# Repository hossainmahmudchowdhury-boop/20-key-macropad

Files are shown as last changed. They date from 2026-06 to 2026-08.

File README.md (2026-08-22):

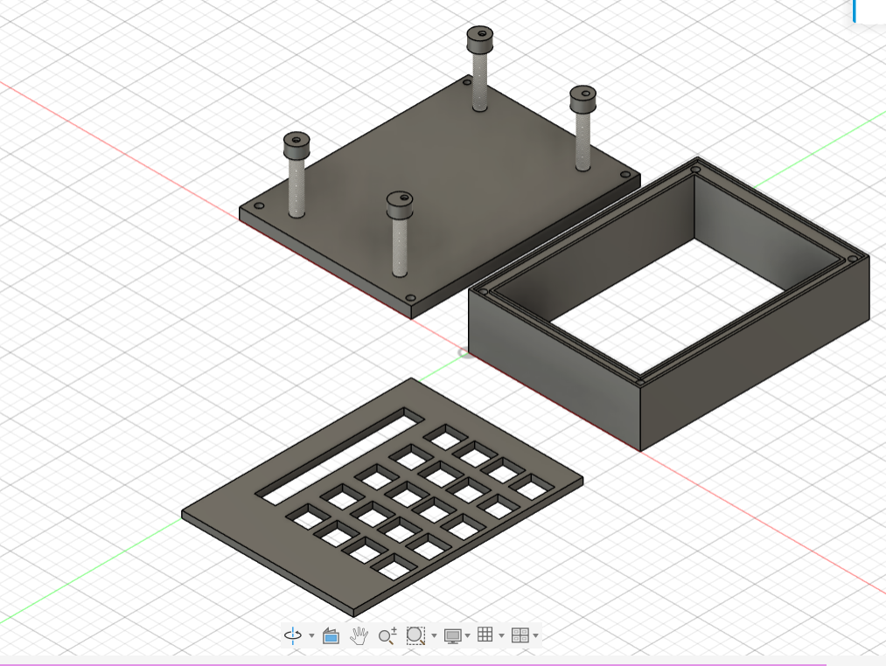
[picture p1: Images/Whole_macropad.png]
image alt

# 20-key-macropad

I have designed a functional macropad design mostly for programming enthusiastics. This design contains 4x5 grid which contains 20 keycaps . Anyone can customize it according to their need . In PCB I have used Seeduino XIAO and for this you can customized the keys in AHK. A potentiometer is also added for operating the macropad with simple matrix design

## Hardware Used

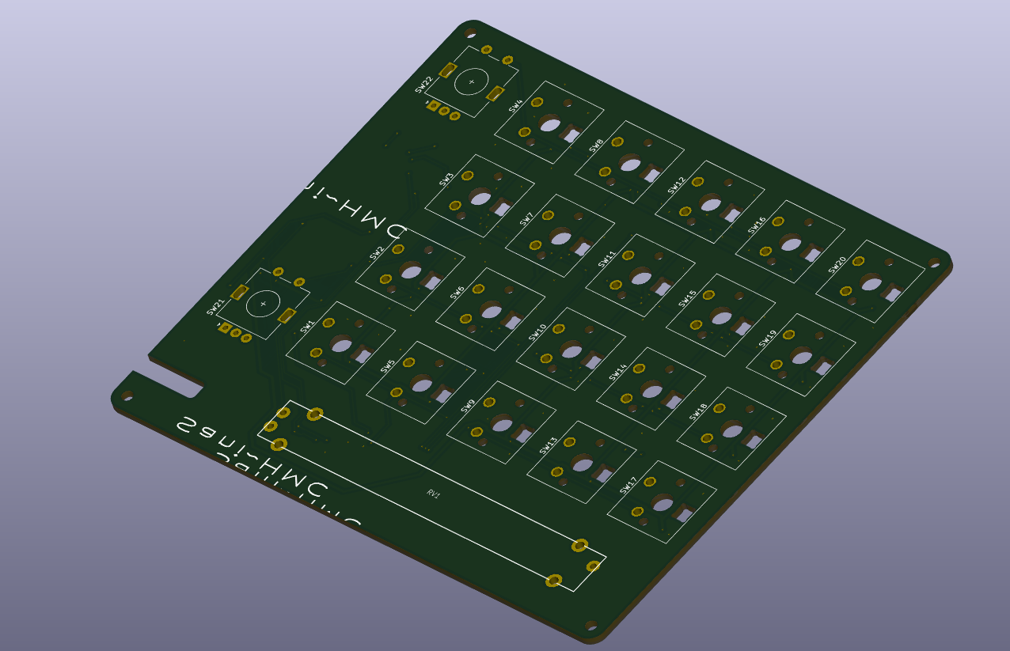
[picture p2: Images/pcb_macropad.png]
image alt

##### Schematic 
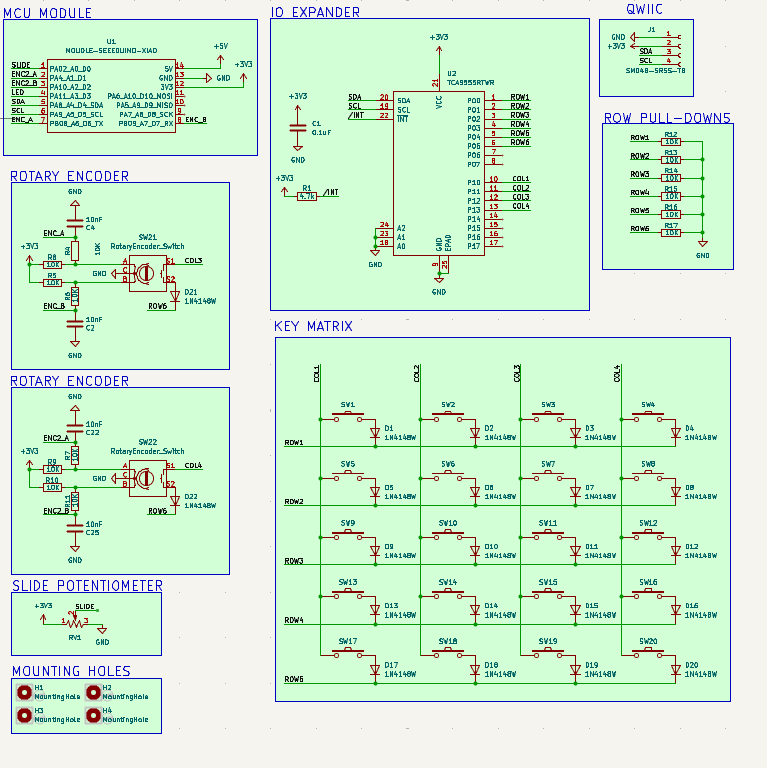
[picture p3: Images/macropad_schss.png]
image alt


#### 1.Seeduino XIAO (MCU)
#### 2.20 × Mechanical Switches
#### 3.20 × Diodes 
#### 4.I/O Expander (for additional key inputs)
#### 5.USB Interface

## Case Design _
As this project emphasizes short way to conduct any command , I made my own custom case in three parts ,
the base one and the top part contain 75mm width and 100mm . The hight of the total case is 32mm  .

### Top Case
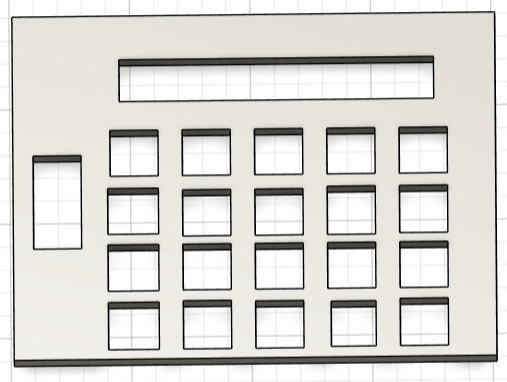
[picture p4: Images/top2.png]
image alt


### Middle Case
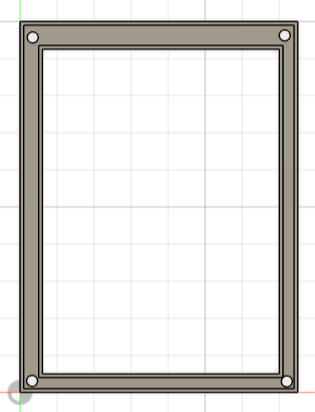
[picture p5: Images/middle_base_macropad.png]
image alt


### Base Case 
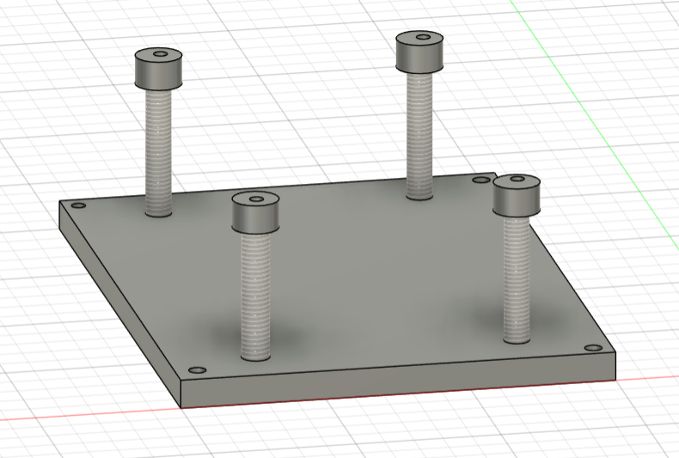
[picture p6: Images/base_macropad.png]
image alt


### Key Cap

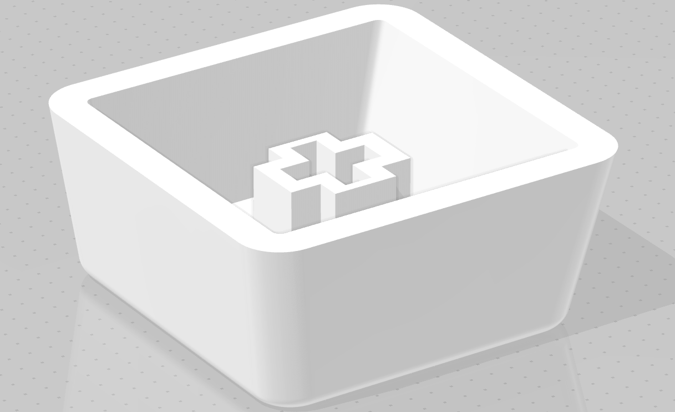
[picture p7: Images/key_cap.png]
image alt


## Software
In this hardware design I use KiCad (Version 10.0) for PCB integration . For case design I have used Fusion . 

## BOM

| Item | Quantity | Price | Link |
|---|---|---|---|
| SEEED XIAO RP2040 (THT) | 1 | $$7.25 | [Link](https://www.seeedstudio.com/XIAO-RP2040-v1-0-p-5026.html) |
| Outemu Silent Peach V3 Switch | 10 | $6.09 | [Link](https://www.aliexpress.com/item/1005006905361113.html) |
| SK6812-MINI-E (RGB LEDs) | 25 | $5.26 | [Link](https://www.aliexpress.com/item/1005005193716172.html) |
| 1N4148 Diode | 100 | $1.20 | [Link](https://www.aliexpress.com/item/4000142272546.html) |
| SSD1306 OLED Display | 1 | $5.15 | [Link](https://www.aliexpress.com/item/1005008640132638.html) |
| YMDK Blank DSA 1u Keycap | 20 | $12.86 | [Link](https://www.aliexpress.com/item/32842379355.html) |
| 45mm Straight Side Potentiometer | 1 | 3.15$ | [Link](https://alishort.com/0HUxU) |
| EC 11 Encoder with Push Button Half Handle 20MM Shaft | 5 | $6.31 | [Link](https://www.aliexpress.com/item/1005005983134515.html) |
| M3 Heat Set Inserts | 30 | $6.13 | [Link](https://www.aliexpress.com/item/1005006071488810.html) |
| M3 Fasteners | 50 | $6.28 | [Link](https://www.aliexpress.com/item/1005011845940916.html) |
| Top Case | 1 | Printing Legion |  |
| Bottom Case | 1 | Printing Legion |  |
| Middle Case | |  Printing Legion | |
| PCB | 3 | $11.02 | JLCPCB |

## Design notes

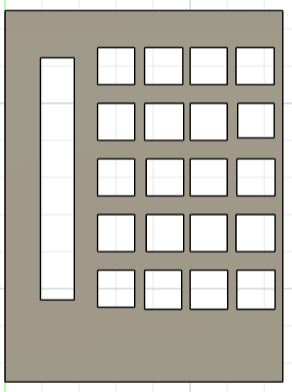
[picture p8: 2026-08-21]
Images/top_macropad.png

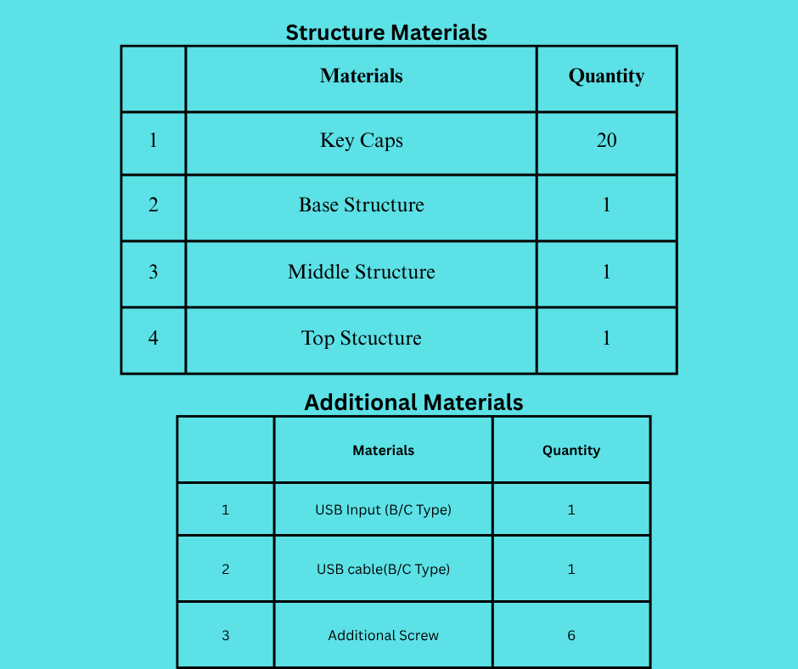
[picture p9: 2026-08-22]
Images/rough_2.png

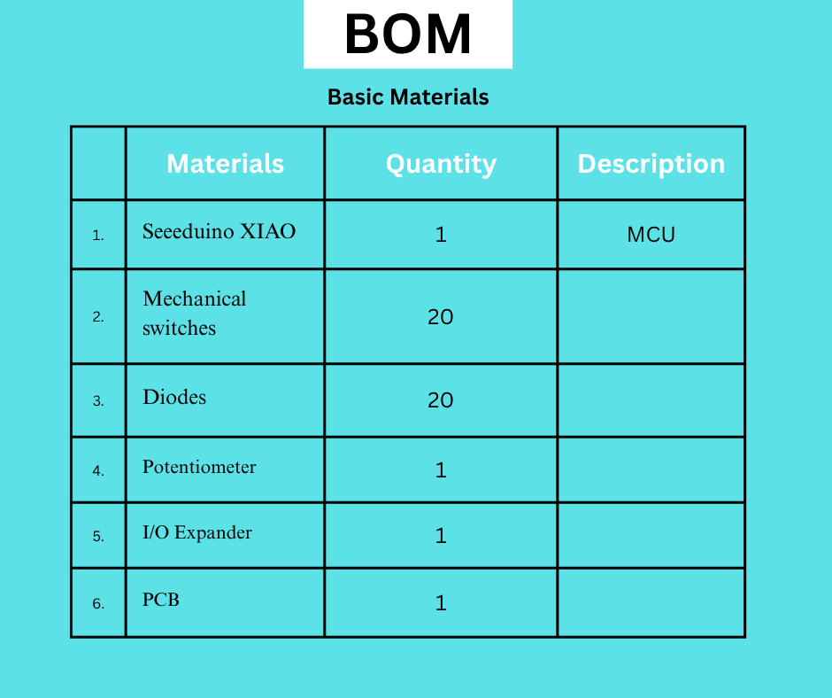
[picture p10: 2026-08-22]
Images/rough_1.png

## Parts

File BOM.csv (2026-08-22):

Item | Quantity | Price | Link
SEEED XIAO RP2040 (THT) | 1 | $7.25 | https://www.seeedstudio.com/XIAO-RP2040-v1-0-p-5026.html
Outemu Silent Peach V3 Switch | 10 | $6.09 | https://www.aliexpress.com/item/1005006905361113.html
SK6812-MINI-E (RGB LEDs) | 20 | $5.26 | https://www.aliexpress.com/item/1005005193716172.html
1N4148 Diode | 100 | $1.20 | https://www.aliexpress.com/item/4000142272546.html
SSD1306 OLED Display | 1 | $5.15 | https://www.aliexpress.com/item/1005008640132638.html
YMDK Blank DSA 1u Keycap | 20 | $12.43 | https://www.aliexpress.com/item/32842379355.html
45mm Straight Side Potentiometer | 1 | 3.15$ | https://alishort.com/0HUxU
EC 11 Encoder with Push Button Half Handle 20MM Shaft | 5 | $6.31 | https://www.aliexpress.com/item/1005005983134515.html
M3 Heat Set Inserts | 30 | $6.13 | https://www.aliexpress.com/item/1005006071488810.html
M3 Fasteners | 50 | $6.28 | https://www.aliexpress.com/item/1005011845940916.html
Top Case | 1 | Printing Legion
Middle Case | 1 | Printing Legion
Bottom Case | 1 | Printing Legion
PCB | 5 | $11.02 | JLCPCB

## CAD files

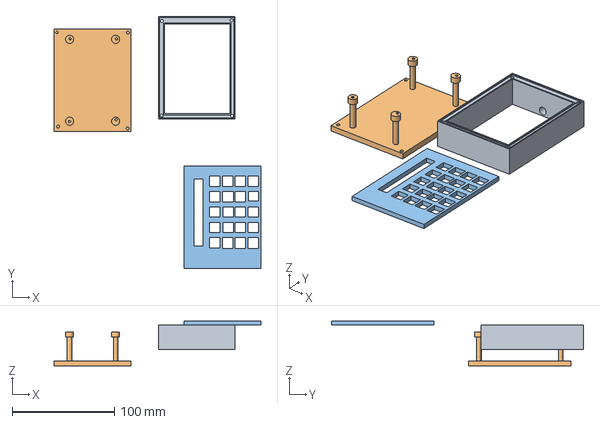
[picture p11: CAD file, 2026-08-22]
Production/Whole_case.step
201.8 x 246.2 x 43.8 mm

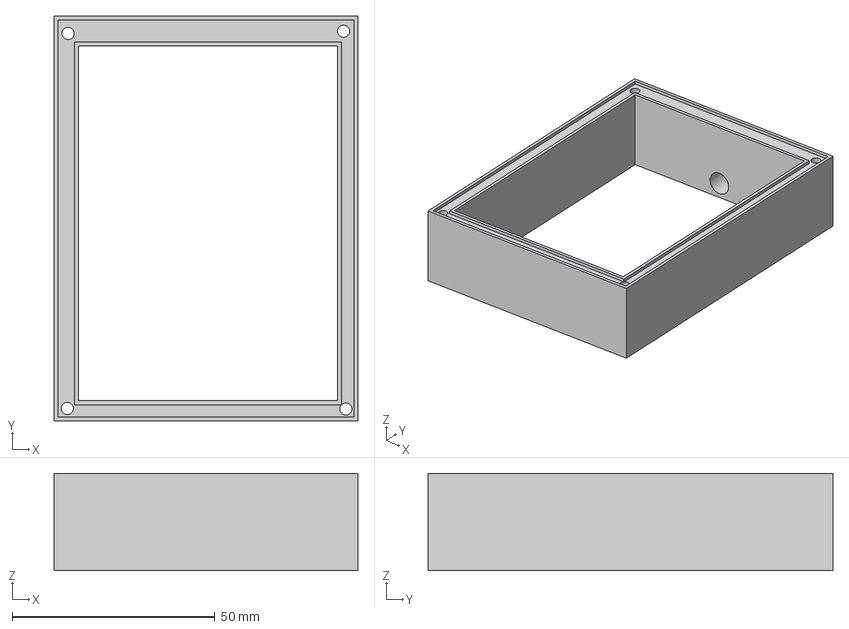
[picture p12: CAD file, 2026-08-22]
Case/middle_macropad.step
75.0 x 100.0 x 24.0 mm

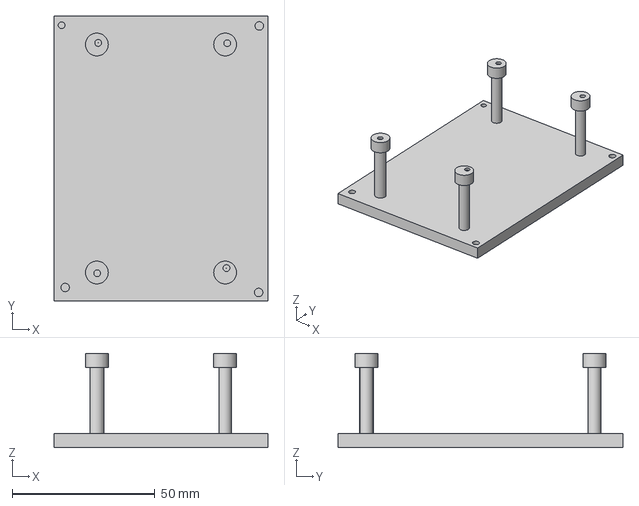
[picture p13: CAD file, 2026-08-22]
Case/base_macropad.step
75.0 x 100.0 x 33.0 mm

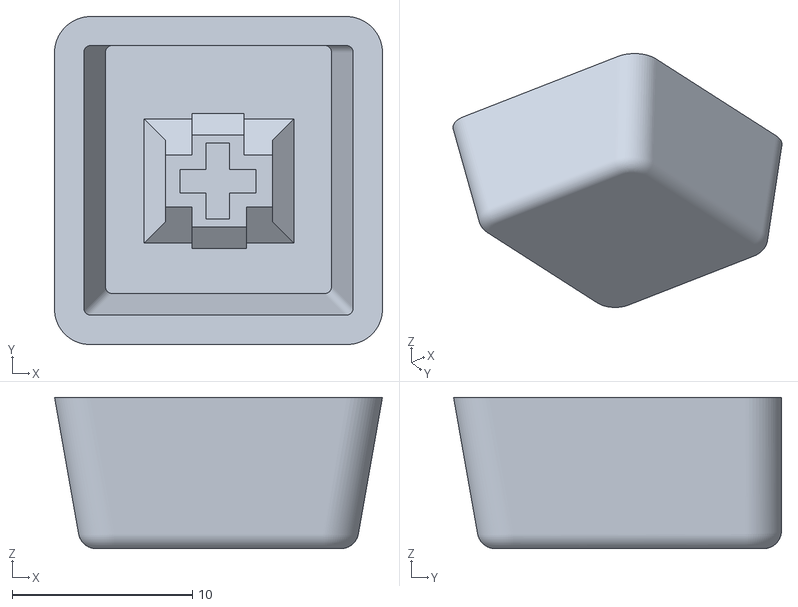
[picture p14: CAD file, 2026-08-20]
Production/Key_Cap_keypad.stl
18.2 x 18.2 x 8.40

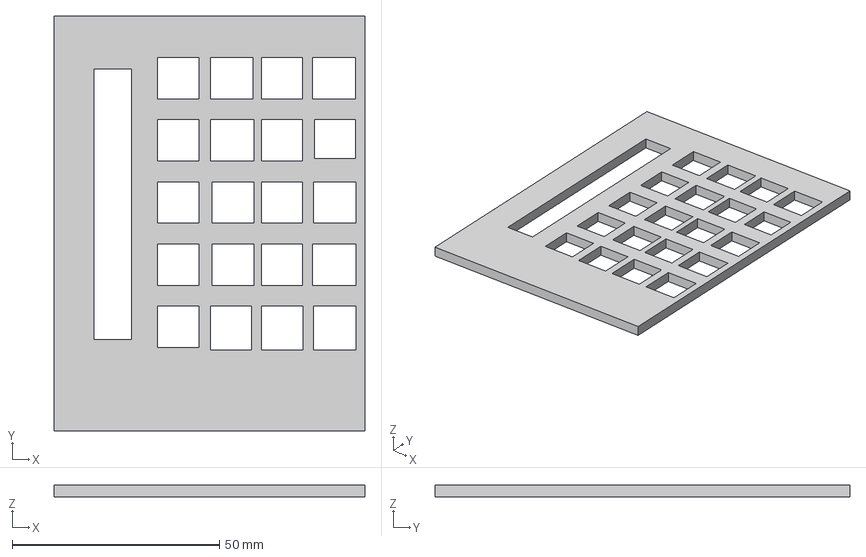
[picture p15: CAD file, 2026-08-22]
Case/top_macropad.step
75.0 x 100.1 x 3.00 mm

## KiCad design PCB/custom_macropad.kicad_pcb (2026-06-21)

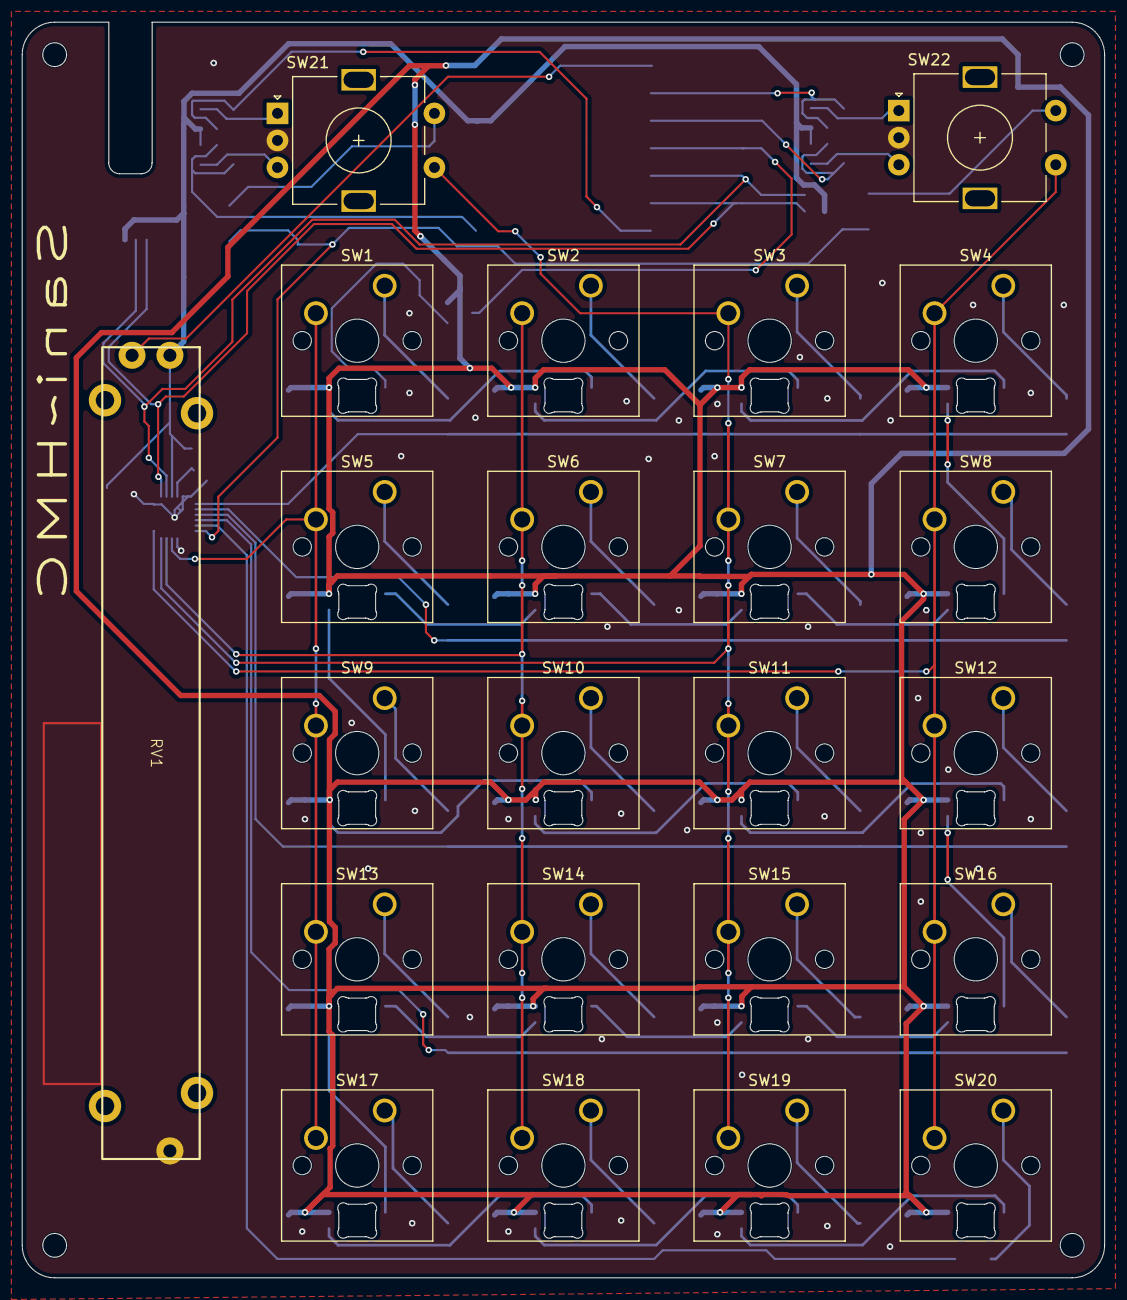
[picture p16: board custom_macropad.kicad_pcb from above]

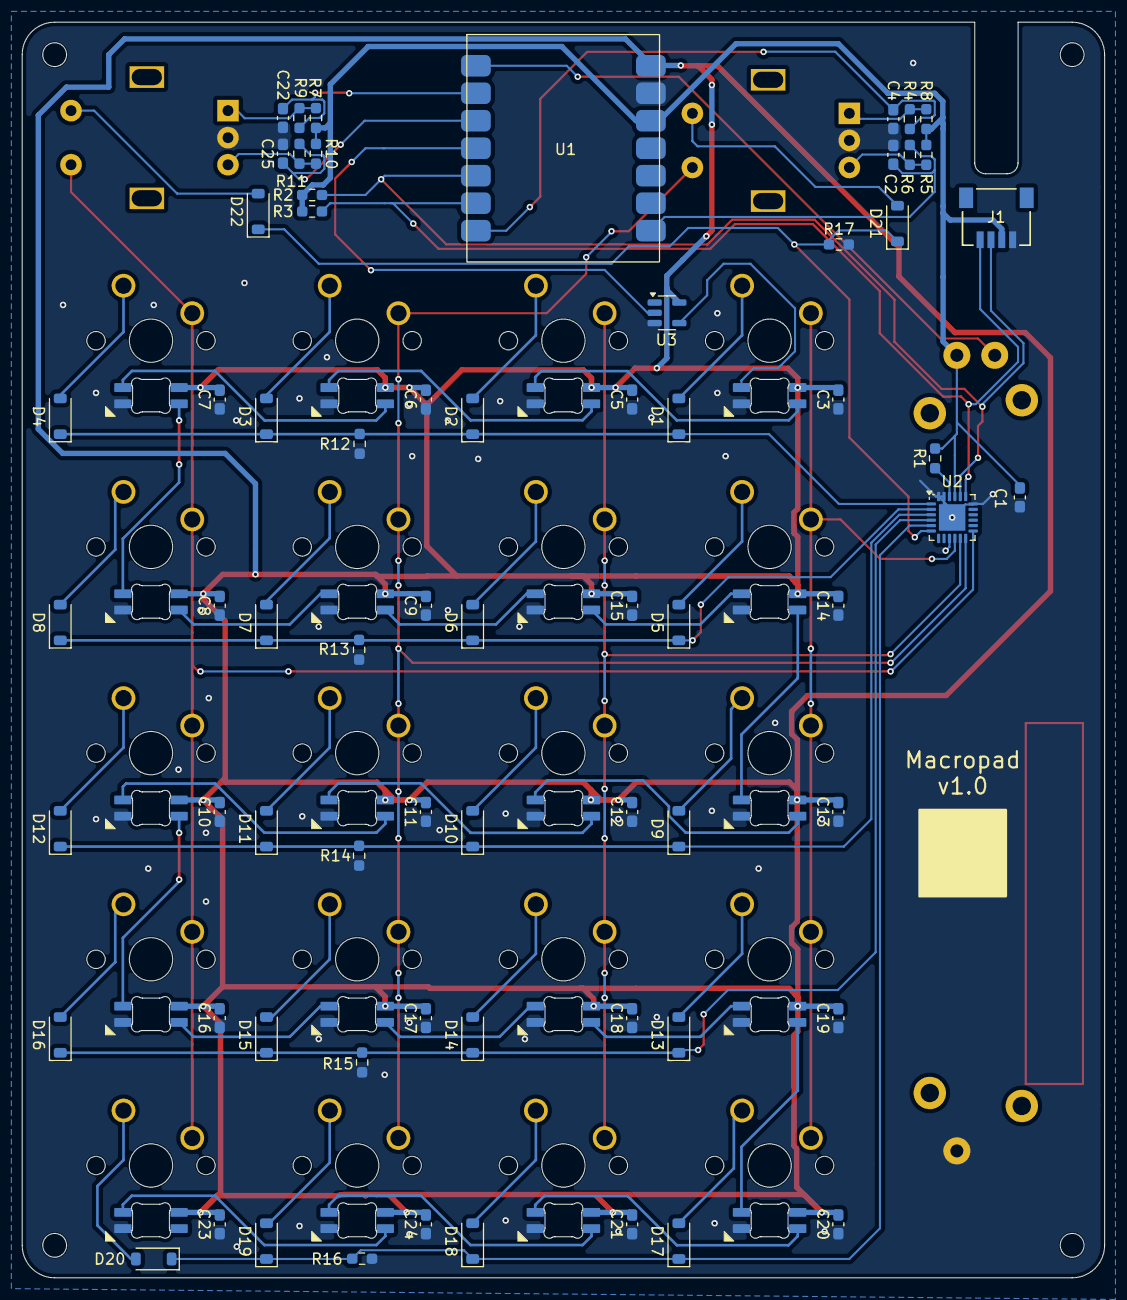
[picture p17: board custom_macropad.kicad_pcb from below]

Board: 2 copper layers, 100.0 x 116.0 mm, 115 parts (68 on the bottom side), 68 nets.

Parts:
C1, C3, C5, C6, C7, C8, C9, C10, C11, C12, C13, C14, C15, C16, C17, C18, C19, C20, C21, C23, C24: 0.1uF; C_0603_1608Metric_Pad1.08x0.95mm_HandSolder
C2, C4, C22, C25: 10nF; C_0603_1608Metric_Pad1.08x0.95mm_HandSolder
D1, D2, D3, D4, D5, D6, D7, D8, D9, D10, D11, D12, D13, D14, D15, D16, D17, D18, D19, D20, D21, D22: 1N4148W; D_SOD-123
H1, H2, H3, H4: MountingHole; MountingHole_2.2mm_M2
J1: SM04B-SRSS-TB; CONN_SM04B-SRSS-TB_JST
LED1, LED2, LED3, LED4, LED5, LED6, LED7, LED8, LED9, LED10, LED11, LED12, LED13, LED14, LED15, LED16, LED17, LED18, LED20, LED21: SK6812MINI-E; MX_SK6812MINI-E
R1, R2, R3: 4.7k; R_0603_1608Metric_Pad0.98x0.95mm_HandSolder
R4, R5, R6, R7, R8, R9, R10, R11, R12, R13, R14, R15, R16, R17: 10K; R_0603_1608Metric_Pad0.98x0.95mm_HandSolder
RV1: R_Potentiometer_US; PTA6043-2010CIB103
SW1, SW2, SW3, SW4, SW5, SW6, SW7, SW8, SW9, SW10, SW11, SW12, SW13, SW14, SW15, SW16, SW17, SW18, SW19, SW20: keyswitch; SW_Cherry_MX_1.00u_PCB
SW21, SW22: RotaryEncoder_Switch; RotaryEncoder_Alps_EC11E-Switch_Vertical_H20mm
U1: MOUDLE-SEEEDUINO-XIAO; MOUDLE14P-SMD-2.54-21X17.8MM
U2: TCA9555RTWR; WQFN-24-1EP_4x4mm_P0.5mm_EP2.45x2.45mm
U3: SN74LV1T34DBV; SOT-23-5

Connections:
+3V3: C1.1, J1.2, R1.2, R2.2, R3.2, R5.1, R8.1, R9.1, R10.1, RV1.1, U1.12 (3V3), U2.21 (VCC)
+5V: C3.2, C5.2, C6.2, C7.2, C8.2, C9.2, C10.2, C11.2, C12.2, C13.2, C14.2, C15.2, C16.2, C17.2, C18.2, C19.2, C20.2, C21.2, C23.2, C24.2, LED1.1 (VDD), LED2.1 (VDD), LED3.1 (VDD), LED4.1 (VDD), LED5.1 (VDD), LED6.1 (VDD), LED7.1 (VDD), LED8.1 (VDD), LED9.1 (VDD), LED10.1 (VDD), LED11.1 (VDD), LED12.1 (VDD), LED13.1 (VDD), LED14.1 (VDD), LED15.1 (VDD), LED16.1 (VDD), LED17.1 (VDD), LED18.1 (VDD), LED20.1 (VDD), LED21.1 (VDD), U1.14 (5V), U3.5 (VCC)
/COL1: SW1.2, SW5.2, SW9.2, SW13.2, SW17.2, U2.10
/COL2: SW2.2, SW6.2, SW10.2, SW14.2, SW18.2, U2.11
/COL3: SW3.2, SW7.2, SW11.2, SW15.2, SW19.2, SW21.S1, U2.12
/COL4: SW4.2, SW8.2, SW12.2, SW16.2, SW20.2, SW22.S1, U2.13
/ENC2_A: C22.2, R7.2, U1.2 (PA4_A1_D1)
/ENC2_B: C25.1, R11.1, U1.3 (PA10_A2_D2)
/ENC_A: C4.2, R4.2, U1.7 (PB08_A6_D6_TX)
/ENC_B: C2.1, R6.1, U1.8 (PB09_A7_D7_RX)
/LED: U1.4 (PA11_A3_D3), U3.2 (A)
/LED_5V: LED1.4 (DIN), U3.4 (Y)
/ROW1: D1.1 (K), D2.1 (K), D3.1 (K), D4.1 (K), R12.1, U2.1 (P00)
/ROW2: D5.1 (K), D6.1 (K), D7.1 (K), D8.1 (K), R13.1, U2.2 (P01)
/ROW3: D9.1 (K), D10.1 (K), D11.1 (K), D12.1 (K), R14.1, U2.3 (P02)
/ROW4: D13.1 (K), D14.1 (K), D15.1 (K), D16.1 (K), R15.1, U2.4 (P03)
/ROW5: D17.1 (K), D18.1 (K), D19.1 (K), D20.1 (K), R16.1, U2.5 (P04)
/ROW6: D21.1 (K), D22.1 (K), R17.1, U2.6 (P05)
/SCL: J1.4, R3.1, U1.6 (PA9_A5_D5_SCL), U2.19 (SCL)
/SDA: J1.3, R2.1, U1.5 (PA8_A4_D4_SDA), U2.20 (SDA)
/SLIDE: RV1.2, U1.1 (PA02_A0_D0)
//INT: R1.1, U2.22 (~INT)
GND: C1.2, C2.2, C3.1, C4.1, C5.1, C6.1, C7.1, C8.1, C9.1, C10.1, C11.1, C12.1, C13.1, C14.1, C15.1, C16.1, C17.1, C18.1, C19.1, C20.1, C21.1, C22.1, C23.1, C24.1, C25.2, J1.1, LED1.3 (VSS), LED2.3 (VSS), LED3.3 (VSS), LED4.3 (VSS), LED5.3 (VSS), LED6.3 (VSS), LED7.3 (VSS), LED8.3 (VSS), LED9.3 (VSS), LED10.3 (VSS), LED11.3 (VSS), LED12.3 (VSS), LED13.3 (VSS), LED14.3 (VSS), LED15.3 (VSS), LED16.3 (VSS), LED17.3 (VSS), LED18.3 (VSS), LED20.3 (VSS), LED21.3 (VSS), R12.2, R13.2, R14.2, R15.2, R16.2, R17.2, RV1.3, SW21.C, SW22.C, U1.13 (GND), U2.9 (GND), U2.18 (A0), U2.23 (A1), U2.24 (A2), U2.25 (EPAD), U3.3 (GND)
unnamed: D1.2 (A), SW1.1
unnamed: D2.2 (A), SW2.1
unnamed: D3.2 (A), SW3.1
unnamed: D4.2 (A), SW4.1
unnamed: D5.2 (A), SW5.1
unnamed: D6.2 (A), SW6.1
unnamed: D7.2 (A), SW7.1
unnamed: D8.2 (A), SW8.1
unnamed: D9.2 (A), SW9.1
unnamed: D10.2 (A), SW10.1
unnamed: D11.2 (A), SW11.1
unnamed: D12.2 (A), SW12.1
unnamed: D13.2 (A), SW13.1
unnamed: D14.2 (A), SW14.1
unnamed: D15.2 (A), SW15.1
unnamed: D16.2 (A), SW16.1
unnamed: D17.2 (A), SW17.1
unnamed: D18.2 (A), SW18.1
unnamed: D19.2 (A), SW19.1
unnamed: D20.2 (A), SW20.1
unnamed: D21.2 (A), SW21.S2
unnamed: D22.2 (A), SW22.S2
unnamed: LED1.2 (DOUT), LED2.4 (DIN)
unnamed: LED2.2 (DOUT), LED3.4 (DIN)
unnamed: LED3.2 (DOUT), LED4.4 (DIN)
unnamed: LED4.2 (DOUT), LED5.4 (DIN)
unnamed: LED5.2 (DOUT), LED6.4 (DIN)
unnamed: LED6.2 (DOUT), LED7.4 (DIN)
unnamed: LED7.2 (DOUT), LED8.4 (DIN)
unnamed: LED8.2 (DOUT), LED9.4 (DIN)
unnamed: LED9.2 (DOUT), LED10.4 (DIN)
unnamed: LED10.2 (DOUT), LED11.4 (DIN)
unnamed: LED11.2 (DOUT), LED12.4 (DIN)
unnamed: LED12.2 (DOUT), LED13.4 (DIN)
unnamed: LED13.2 (DOUT), LED14.4 (DIN)
unnamed: LED14.2 (DOUT), LED15.4 (DIN)
unnamed: LED15.2 (DOUT), LED16.4 (DIN)
unnamed: LED16.2 (DOUT), LED17.4 (DIN)
unnamed: LED17.2 (DOUT), LED18.4 (DIN)
unnamed: LED18.2 (DOUT), LED21.4 (DIN)
unnamed: LED20.4 (DIN), LED21.2 (DOUT)
unnamed: R4.1, R8.2, SW21.A
unnamed: R5.2, R6.2, SW21.B
unnamed: R7.1, R9.2, SW22.A
unnamed: R10.2, R11.2, SW22.B

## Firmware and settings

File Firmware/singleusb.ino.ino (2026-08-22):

#include <Adafruit_TinyUSB.h>

// Define the button pin
#define BUTTON_PIN 2

// Track the button state
bool buttonState = false;
bool lastButtonState = false;

void setup() {
  pinMode(BUTTON_PIN, INPUT_PULLUP);  // Internal pull-up resistor
  TinyUSBDevice.begin();  // Start TinyUSB
  delay(1000);  // Allow some startup time
}

void loop() {
  // Read the current state of the button
  buttonState = digitalRead(BUTTON_PIN);

  // Detect a button press (transition from HIGH to LOW)
  if (buttonState == LOW && lastButtonState == HIGH) {
    sendKeyPress();
  }

  // Update the last state
  lastButtonState = buttonState;

  delay(10);  // Debounce delay
}

void sendKeyPress() {
  // Send the letter 'a' to the computer
  TinyUSBKeyboard.print("a");
}

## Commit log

2026-08-22 Add schematic image to README
    Added schematic image to README for clarity.
2026-08-22 Update README.md
    Removed BOM images from the README.
2026-08-22 Update BOM.csv
    Added new components with quantities and prices to BOM.
    [BOM.csv]
2026-08-22 Add Middle Case to BOM
    [BOM.csv]
2026-08-22 Add 45mm Straight Side Potentiometer to BOM
    Added a new component, 45mm Straight Side Potentiometer, to the BOM with its price and link.
    [BOM.csv]
2026-08-22 Update BOM section in README with new link format
2026-08-22 Update BOM table with component details and links
